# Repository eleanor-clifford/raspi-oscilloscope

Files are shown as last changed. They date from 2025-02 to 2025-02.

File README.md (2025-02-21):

| :exclamation:  | This is a mirror of [https://git.sr.ht/~ecc/raspi-oscilloscope](https://git.sr.ht/~ecc/raspi-oscilloscope). Please refrain from using GitHub's issue and PR system.  |
|---|:---|

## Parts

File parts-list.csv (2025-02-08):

Name | Part No. | Purpose | Value | Cost
RPi | RPi 1A rev 2 | Microprocessor | - | 0+
U1 | ECS-2200B-100 | Clock generator | 10 MHz | 1.96
U2 | TLC5510INSR | ADC | 20 MHz 8-bit parallel | 5.38
U3 | OPA690 | Op amp | 5V min unipolar | 3.01
U4 | SN74LS245N | Logic level converter | 5V - 3V3 | 2.99
D1 | NZX3V9C | ADC overvolt protection | 4V | 0.16
D2 | NZX5V1B | Op amp reverse/overvolt protection | 3V | 0.16
C1 | - | Input coupling | 100nF ceramic | 0+
C2 | - | Analog bypass | 100nF ceramic | 0+
C3 | - | Digital bypass | 100nF ceramic | 0+
C4 | - | Reference bypass | 100nF ceramic | 0+
C5 | - | Analog bypass | 4.7uF electrolytic | 0*
C6 | - | Digital bypass | 4.7uF electrolytic | 0*
C7 | - | Reference bypass | 4.7uF electrolytic | 0*
SW1 | SR10010F-0106-20F0B-C7-N-0027 | Op amp gain switch | SP6T | 5.19
R1 | - | Op amp gain (low) | 470 | 0+
R2 | - | ADC reference (high) | 82 | 0+
R3 | - | ADC reference (low) | 330 | 0+
R4 | - | Op amp bias (high) | 1.5k | 0+
R5 | - | Op amp bias (low) | 1k | 0+
R6 | - | Op amp input | 47 | 0+
R7 | - | ADC input | 47 | 0+
R8 | - | Op amp gain (10x) | 4k7 | 0+
R9 | - | Op amp gain (100x) | 47k | 0+
A1 | - | ADC adapter | SOP-24 to DIP-24 | 1.67-
A2 | - | Op amp adapter | SOP-4 to DIP-4 | 1.52-
B1 | PAD1 | Circuit board | DIP 31x19 | 3.42
J1 | 1-1337543-0 | Probe connector | BNC | 1.15
J2 | - | Data header | 1x8 2.54mm | 2.69-
J3 | - | Analog power header | 1x2 2.54mm | -
- | CQ4LF | Flux | Liquid, No-Clean | 6.30
- | CT2703 | Probe | 60MHz x1/x10 | 12.91
 |  |  | Total | 45.52
* | scavenged |  | VAT | 7.93
+ | bought earlier
- | includes extra components |  | Grand Total | 56.44

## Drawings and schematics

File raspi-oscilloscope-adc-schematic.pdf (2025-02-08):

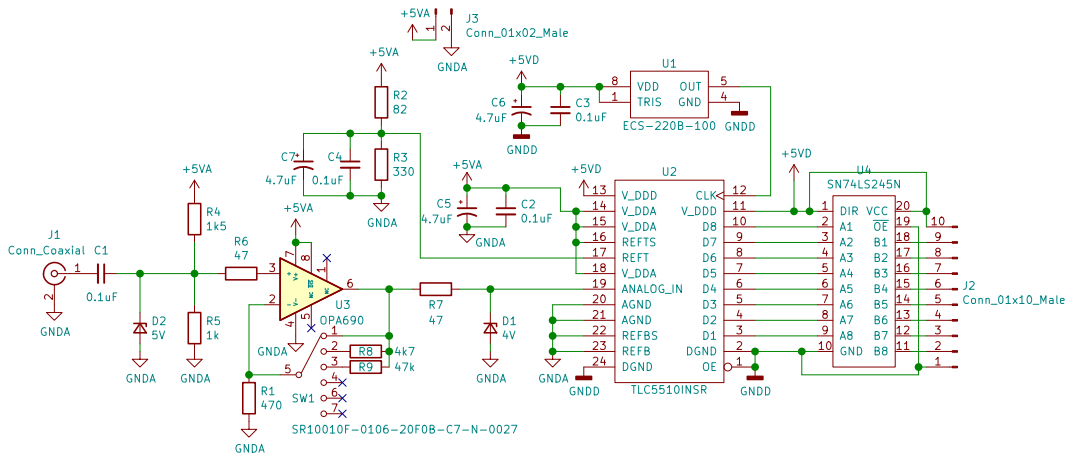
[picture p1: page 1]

Operates at 10Msps
Analog and digital power rails should ideally be isolated
Output will saturate at 4Vpp input
File: raspi-oscilloscope-adc.sch Sheet: / Designed by Tim Clifford

Id: 1/1 Title: Raspberry Pi oscilloscope ADC board

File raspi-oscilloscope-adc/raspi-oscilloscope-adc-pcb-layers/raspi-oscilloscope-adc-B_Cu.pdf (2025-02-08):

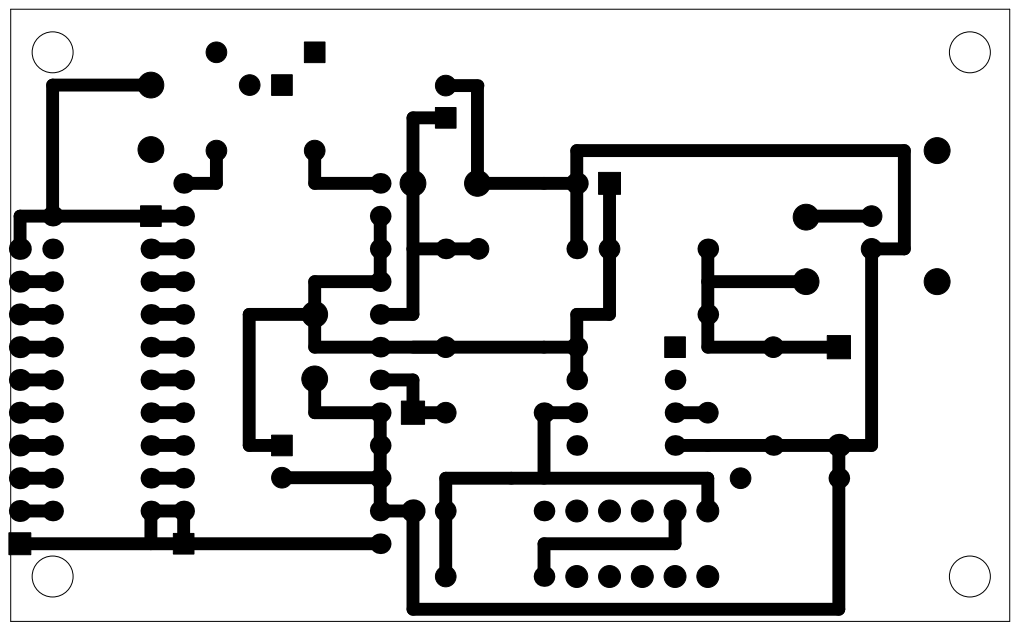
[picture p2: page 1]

Intended for implementation on 31x19 DIP busboard
Top level traces should be replaced by wires except around oscillator
U2 and U3 are intended as SOP packages on SOP-DIP adapters
File: raspi-oscilloscope-adc.kicad_pcb Sheet: Designed by Tim Clifford

Id: 1/1 Title: Raspberry Pi oscilloscope ADC board

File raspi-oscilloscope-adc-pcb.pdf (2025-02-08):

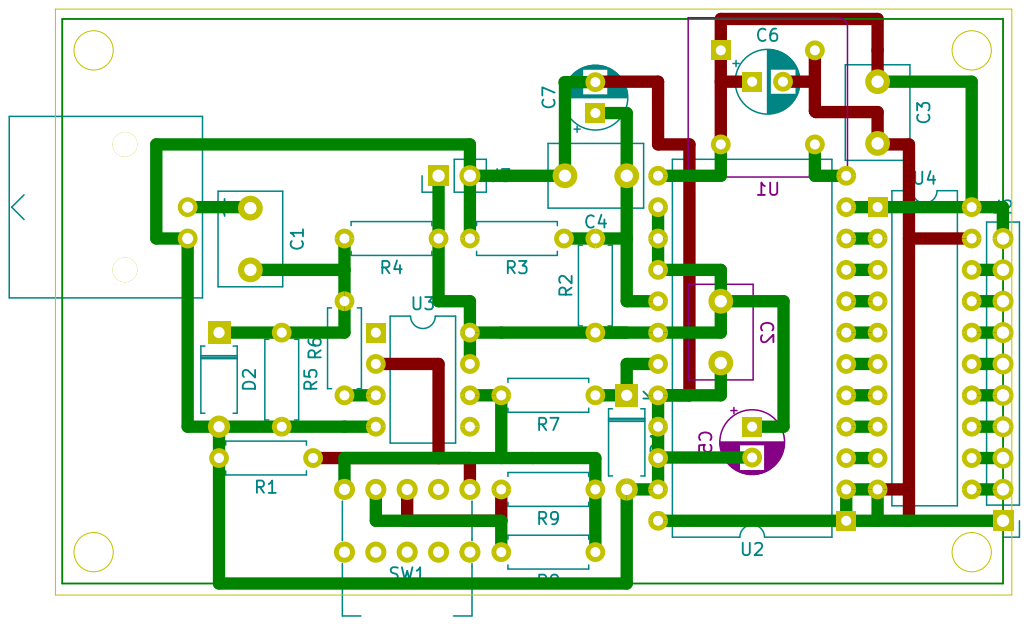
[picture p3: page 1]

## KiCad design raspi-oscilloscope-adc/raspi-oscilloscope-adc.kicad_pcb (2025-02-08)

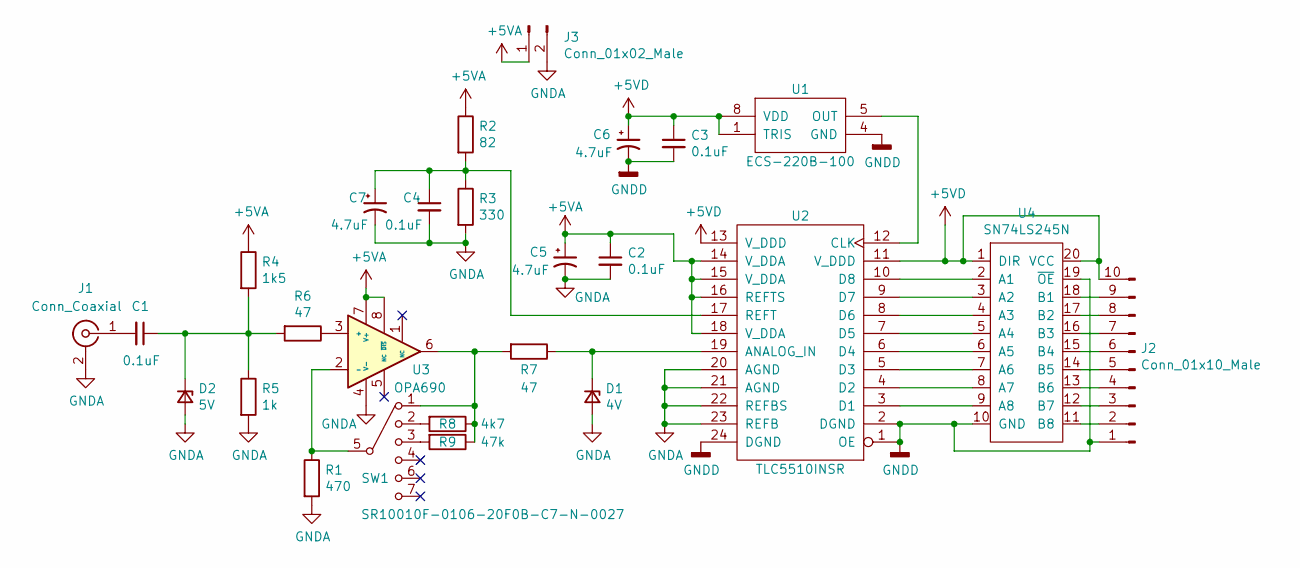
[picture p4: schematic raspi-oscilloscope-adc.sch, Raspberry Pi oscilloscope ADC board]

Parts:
C1, C2, C3, C4: 0.1uF; C_Disc_D7.5mm_W5.0mm_P5.00mm
C5, C6, C7: 4.7uF; CP_Radial_D5.0mm_P2.50mm
D1: 4V; D_A-405_P7.62mm_Horizontal
D2: 5V; D_A-405_P7.62mm_Horizontal
J1: Conn_Coaxial; 1-1337543-0
J2: Conn_01x10_Male; PinHeader_1x10_P2.54mm_Vertical
J3: Conn_01x02_Male; PinHeader_1x02_P2.54mm_Vertical
R1: 470; R_Axial_DIN0207_L6.3mm_D2.5mm_P7.62mm_Horizontal
R2: 82; R_Axial_DIN0207_L6.3mm_D2.5mm_P7.62mm_Horizontal
R3: 330; R_Axial_DIN0207_L6.3mm_D2.5mm_P7.62mm_Horizontal
R4: 1k5; R_Axial_DIN0207_L6.3mm_D2.5mm_P7.62mm_Horizontal
R5: 1k; R_Axial_DIN0207_L6.3mm_D2.5mm_P7.62mm_Horizontal
R6, R7: 47; R_Axial_DIN0207_L6.3mm_D2.5mm_P7.62mm_Horizontal
R8: 4k7; R_Axial_DIN0207_L6.3mm_D2.5mm_P7.62mm_Horizontal
R9: 47k; R_Axial_DIN0207_L6.3mm_D2.5mm_P7.62mm_Horizontal
SW1: SR10010F-0106-20F0B-C7-N-0027; SW_SP6T
U1: ECS-220B-100; Oscillator_DIP-8
U2: TLC5510INSR; DIP-24_W15.24mm
U3: OPA690; DIP-8_W7.62mm
U4: SN74LS245N; DIP-20_W7.62mm

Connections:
+5VA: C2.1, C5.1, J3.1, R2.1, R4.1, U2.14 (V_DDA), U2.15 (V_DDA), U2.16 (REFTS), U2.18 (V_DDA), U3.7 (V+), U3.8 (~DIS)
+5VD: C3.1, C6.1, J2.10, U1.1 (TRIS), U1.8 (VDD), U2.11 (V_DDD), U2.13 (V_DDD), U4.1 (DIR), U4.20 (VCC)
GNDA: C2.2, C4.2, C5.2, C7.2, D1.2 (A), D2.2 (A), J1.2 (Ext), J3.2, R1.2, R3.2, R5.2, U2.20 (AGND), U2.21 (AGND), U2.22 (REFBS), U2.23 (REFB), U3.4 (V-)
GNDD: C3.2, C6.2, J2.1, U1.4 (GND), U2.1 (OE), U2.2 (DGND), U2.24 (DGND), U4.10 (GND), U4.19 (~OE)
unnamed: C1.1, D2.1 (K), R4.2, R5.1, R6.2
unnamed: C1.2, J1.1 (In)
unnamed: C4.1, C7.1, R2.2, R3.1, U2.17 (REFT)
unnamed: D1.1 (K), R7.1, U2.19 (ANALOG_IN)
unnamed: J2.2, U4.11 (B8)
unnamed: J2.3, U4.12 (B7)
unnamed: J2.4, U4.13 (B6)
unnamed: J2.5, U4.14 (B5)
unnamed: J2.6, U4.15 (B4)
unnamed: J2.7, U4.16 (B3)
unnamed: J2.8, U4.17 (B2)
unnamed: J2.9, U4.18 (B1)
unnamed: R1.1, SW1.5, U3.2 (-)
unnamed: R6.1, U3.3 (+)
unnamed: R7.2, R8.1, R9.1, SW1.1, U3.6
unnamed: R8.2, SW1.2
unnamed: R9.2, SW1.3
unnamed: U1.5 (OUT), U2.12 (CLK)
unnamed: U2.3 (D1), U4.9 (A8)
unnamed: U2.4 (D2), U4.8 (A7)
unnamed: U2.5 (D3), U4.7 (A6)
unnamed: U2.6 (D4), U4.6 (A5)
unnamed: U2.7 (D5), U4.5 (A4)
unnamed: U2.8 (D6), U4.4 (A3)
unnamed: U2.9 (D7), U4.3 (A2)
unnamed: U2.10 (D8), U4.2 (A1)

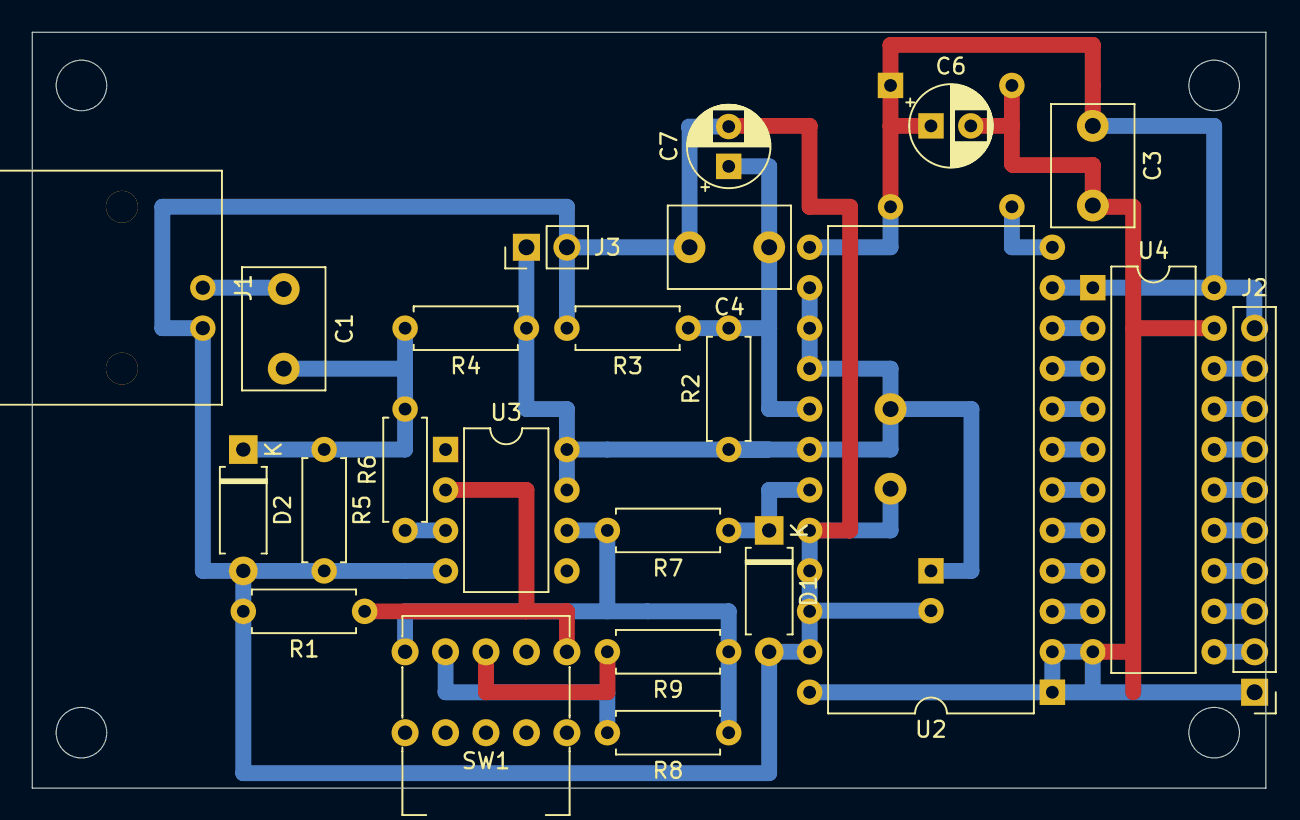
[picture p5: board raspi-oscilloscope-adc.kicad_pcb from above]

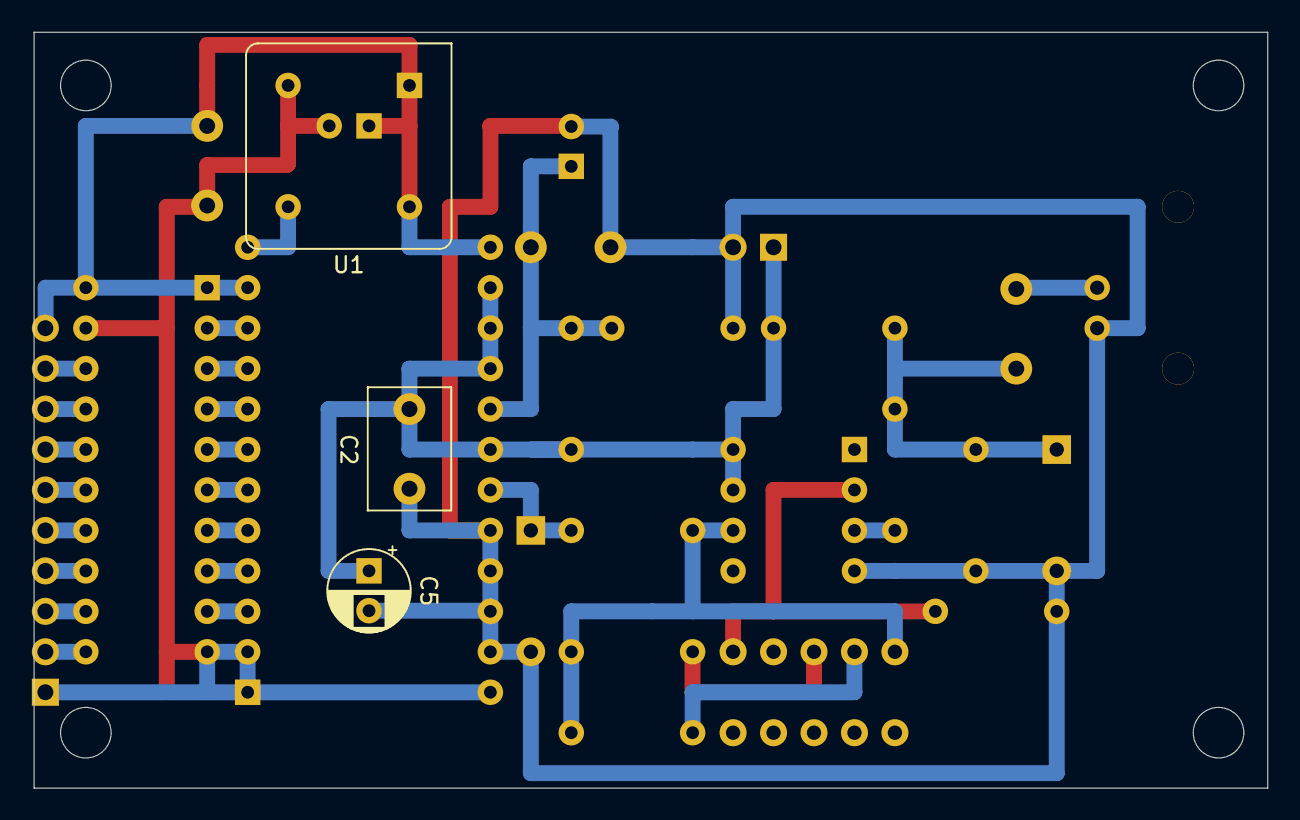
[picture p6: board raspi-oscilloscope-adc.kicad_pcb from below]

Board: 2 copper layers, 77.5 x 47.5 mm, 26 parts (3 on the bottom side), 30 nets.

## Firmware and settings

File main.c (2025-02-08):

//  GPIO Access macros
//  15-January-2012
//  Dom and Gert
//  Revised: 15-Feb-2013
// Access from ARM Running Linux

#define BCM2708_PERI_BASE        0x20000000
#define GPIO_BASE                (BCM2708_PERI_BASE + 0x200000) /* GPIO controller */

#include <stdio.h>
#include <stdlib.h>
#include <fcntl.h>
#include <sys/mman.h>
#include <sys/time.h>
#include <unistd.h>

#define PAGE_SIZE (4*1024)
#define BLOCK_SIZE (4*1024)

int  mem_fd;
void *gpio_map;

// I/O access
volatile unsigned *gpio;


// GPIO setup macros. Always use INP_GPIO(x) before using OUT_GPIO(x) or SET_GPIO_ALT(x,y)
#define INP_GPIO(g) *(gpio+((g)/10)) &= ~(7<<(((g)%10)*3))
#define OUT_GPIO(g) *(gpio+((g)/10)) |=  (1<<(((g)%10)*3))
#define SET_GPIO_ALT(g,a) *(gpio+(((g)/10))) |= (((a)<=3?(a)+4:(a)==4?3:2)<<(((g)%10)*3))

#define GPIO_SET *(gpio+7)  // sets   bits which are 1 ignores bits which are 0
#define GPIO_CLR *(gpio+10) // clears bits which are 1 ignores bits which are 0

#define GET_GPIO(g) (*(gpio+13)&(1<<g)) // 0 if LOW, (1<<g) if HIGH
#define GET_GPIO_ALL *(gpio+13)

#define GPIO_PULL *(gpio+37) // Pull up/pull down
#define GPIO_PULLCLK0 *(gpio+38) // Pull up/pull down clock


// Uses code from Raspberry Compote http://raspberrycompote.blogspot.com/2012/12/low-level-graphics-on-raspberry-pi-part_9509.html
// and glyphs from JSBallista https://github.com/JSBattista/Characters_To_Linux_Buffer_THE_HARD_WAY

#include <string.h>
#include <linux/fb.h>
#include <sys/ioctl.h>
#include <time.h>
#include <math.h>
#include "EngNotation.h"
// These are the sizes of the individual character arrays
#define CHAR_ARR__10x14 168
#define CHAR_HEIGHT 14
#define CHAR_WIDTH 10
#define CHAR_SPACING 15
const unsigned char *ascii_characters[256];	// Store the ASCII character set, but can have some elements blank
struct fb_var_screeninfo orig_vinfo;
struct fb_var_screeninfo vinfo;
struct fb_fix_screeninfo finfo;
long int screensize;
void setup_chars();
void display_ascii(char *fbp, char c, int x, int y);
void clear_framebuffer(char *fbp);
void draw_background(char *fbp, double t);
void draw_rising_trigger(char *fbp, u_int8_t *data, int data_len, u_int8_t trigger_low, u_int8_t trigger_high);
void setup_io();
void setup_framebuffer();
void cleanup_framebuffer();
char *fbp = 0;
int fbfd = 0;
void request_data(int data_len, int delay_usec, u_int8_t *data);

// application entry point
int main(int argc, char* argv[])
{
    srand(time(NULL));
    setup_chars();
    setup_framebuffer();
    setup_io();
    // scope time...
    u_int8_t *data = malloc(512*sizeof(u_int8_t));
    clear_framebuffer(fbp);
    // scope
	while (1) {
		draw_background(fbp, 1.234e-9);
		request_data(512,0,data);
		draw_rising_trigger(fbp,data,512,16,240);
		//printf("%x\n",data[256]);
	}
	free(data);
  //  sleep(5);

  	cleanup_framebuffer();
  	return 0;
}
void display_ascii(char *fbp, char c, int x, int y)
{
    int yi;
    for (yi = 0; yi < CHAR_HEIGHT; yi++) {
        memcpy((char*)(fbp + x + (y+yi)*finfo.line_length),(char*)(ascii_characters[c] + CHAR_WIDTH*yi),CHAR_WIDTH*sizeof(u_int8_t));
    }
}
void clear_framebuffer(char *fbp) {
	int i;
	for (i = 0; i < vinfo.yres*vinfo.xres; i++) fbp[i] = 0;
}
void draw_background(char *fbp, double t) {
    // create fixed background grid
    // we will use 512x256px for the actual trace, and a resolution of 640x360px
    // (8 bit ADC results in 256 levels so there's no point quantising to something else and losing information)
    // assume for now that timestep is constant t
    // although it defo won't be lol
    // lets split into 8x4 squares because why not. So lines at 64px and why not tick at 8px
    // leave 52px left/right and 64px up/down
    // i don't care too much about efficiency here because it will be executed infrequently
    int x,y;
    for (x = 52; x < 564; x++) {
        for (y = 64; y < 320; y++) {
            if ((x-52)%64 == 0 || y%64 == 0) fbp[x + y * finfo.line_length] = 2;
            else {
                int xrel = (x-52)%64;
                int yrel = y%64;
                if ((x-52)%8 == 0 && (yrel < 4 || yrel > 60)) fbp[x + y * finfo.line_length] = 2;
                if (y%8 == 0 && (xrel < 4 || xrel > 60)) fbp[x + y * finfo.line_length] = 2;
            }
        }
    }
    // write timestep in full up top then round for the markings
    char *t_eng_notation = to_engineering_string(t,8,0);
    char *test_string = "ABCDEFGHIJKkLMmNOPQRSsTUuVWXYZ\0";
    int i = 0;
    do {
        display_ascii(fbp, test_string[i], 10+i*CHAR_SPACING, 10);
    } while (test_string[++i] != '\0');
    char *test_string_2 = "0123456789\0";
    i = 0;
    do {
        display_ascii(fbp, test_string_2[i], 10+i*CHAR_SPACING, 30);
    } while (test_string_2[++i] != '\0');
	free(t_eng_notation);
}
void request_data(int data_len, int delay_usec, u_int8_t *data) {
	u_int16_t raw_data;
	int i;
	for (i=0; i<data_len; i++)
	{
		raw_data = GET_GPIO_ALL;
		data[i] = ((raw_data >> 4) & 248) | ((raw_data >> 2) & 7);
		if (delay_usec) usleep(delay_usec);
	}
}
void draw_rising_trigger(char *fbp, u_int8_t *data, int data_len, u_int8_t trigger_low, u_int8_t trigger_high) {
    /* Trigger the signal based on an average of the times 
     * when the signal passes a high and low trigger
     *  |   /\         |   /\ 
     *  |  /  \        |  /  \
     *  |_/____\_______|_/____\____ high trigger
     *  |/      \      |/      \
     *_/|________\____/|________\__ low trigger
     *  |         \  / |
     *  |          \/  |            vertical lines will be centered on screen
     * 
     * this allows noise within trigger levels without it spasming on screen
     *
     * making this low efficiency now, will have to optimise later
     * prioritise low memory use, since `data` should fill
     * as much of main memory as possible
     */
    // find rising edges
    int i,j;
    bool low = false; // data was above low trigger
    bool high = false; // data has hit high trigger (resets on low)
    int low_marker = 0; // the index where signal rose above low trigger
    int trigger_marker; // index to trigger on
    int t_scaling = 1; // we will want later to skip/amalgamate some of the datapoints to show higher frequencies
    int startval,endval;
    //int last_trigger = 0;
    //double t_avg = 0; // average period so far (in units of timestep)
    //int rise_counter = 0
    u_int8_t *linebuffer = calloc(512,sizeof(u_int8_t)); // buffer of last value drawn to screen at this position
    // this means we can erase and write at the same position with minimal latency so that something is on the screen at all times
    for (i = 0; i < data_len; i++) {
        //printf("i: %d, data: %d\n",i,data[i]);
        if (data[i] > trigger_high) {
            if (!high) {

                if (!low) {
                    low_marker = i;
                    low = true;
                }
                trigger_marker = (int)(i + low_marker)/2; // close enough
                //t_avg = (t_avg*(rise_counter++) + trigger_marker)/rise_counter;
                // for now, lets just redraw on every rising edge, but
                // in future it's not worth it when several waveforms may be on screen
                if (trigger_marker < 256) startval = 0;
                else startval = trigger_marker - 256;
                if (trigger_marker + 256 > data_len) endval = data_len-1;
                else endval = trigger_marker + 256;
                //printf("st: %d tr: %d en: %d\n",startval,trigger_marker,endval);
                //sleep(1);
                for (j = startval; j < endval; j++) {
                //    printf("j: %d data: %d\n",j,data[j]);
                    // clear the pixel at this point in the linebuffer
                    fbp[308 + j - trigger_marker + (64+linebuffer[256+j-trigger_marker]) * finfo.line_length] = 0;
                    // set new pixel
                    fbp[308 + j - trigger_marker + (64+data[j]) * finfo.line_length] = 1; // 308 = 52 + 256, 52 is zero point
                    // write into linebuffer at new position
                    linebuffer[256+j-trigger_marker] = data[j];
                }
                usleep(100000); // wait to make sure it actually shows up
				// just for debugging
				clear_framebuffer(fbp);

				draw_background(fbp,0);
                high = true; // now wait until below low
            }
        }
        else if (data[i] > trigger_low) {
            if (!low) {
                low = true; // data has hit low trigger
                low_marker = i;
            }
        }
        else {
            high = false;
            low = false;
        }
    }
	free(linebuffer);
     
}
void setup_io()
{
	/* open /dev/mem */
	if ((mem_fd = open("/dev/mem", O_RDWR|O_SYNC) ) < 0) {
		printf("can't open /dev/mem \n");
		exit(-1);
	}

	/* mmap GPIO */
	gpio_map = mmap(
	   NULL,             //Any adddress in our space will do
	   BLOCK_SIZE,       //Map length
	   PROT_READ|PROT_WRITE,// Enable reading & writting to mapped memory
	   MAP_SHARED,       //Shared with other processes
	   mem_fd,           //File to map
	   GPIO_BASE         //Offset to GPIO peripheral
	);

	close(mem_fd); //No need to keep mem_fd open after mmap

	if (gpio_map == MAP_FAILED) {
		printf("mmap error %d\n", (int)gpio_map);//errno also set!
		exit(-1);
	}

   // Always use volatile pointer!
   gpio = (volatile unsigned *)gpio_map;
   
   // set inputs from ADC
   int g;
   for (g=2; g<= 4; g++) INP_GPIO(g);
   for (g=7; g<=11; g++) INP_GPIO(g);

}
void setup_framebuffer() {
  
  screensize = 0;
  // Open the file for reading and writing
  fbfd = open("/dev/fb0", O_RDWR);
  if (!fbfd) {
    printf("Error: cannot open framebuffer device.\n");
    exit(1);
  }
  printf("The framebuffer device was opened successfully.\n");

  // Get variable screen information
  if (ioctl(fbfd, FBIOGET_VSCREENINFO, &vinfo)) {
    printf("Error reading variable information.\n");
  }
  printf("Original %dx%d, %dbpp\n", vinfo.xres, vinfo.yres, 
         vinfo.bits_per_pixel );

  // Store for reset (copy vinfo to vinfo_orig)
  memcpy(&orig_vinfo, &vinfo, sizeof(struct fb_var_screeninfo));

  // Change variable info
  vinfo.bits_per_pixel = 8;
  if (ioctl(fbfd, FBIOPUT_VSCREENINFO, &vinfo)) {
    printf("Error setting variable information.\n");
  }
  
  // Get fixed screen information
  if (ioctl(fbfd, FBIOGET_FSCREENINFO, &finfo)) {
    printf("Error reading fixed information.\n");
  }

  // map fb to user mem 
  screensize = finfo.smem_len;
  fbp = (char*)mmap(0, 
                    screensize, 
                    PROT_READ | PROT_WRITE, 
                    MAP_SHARED, 
                    fbfd, 
                    0);

  if ((int)fbp == -1) {
    printf("Failed to mmap.\n");
	exit(1);
  }
}
void cleanup_framebuffer() {
	// cleanup
  	munmap(fbp, screensize);
  	if (ioctl(fbfd, FBIOPUT_VSCREENINFO, &orig_vinfo)) {
    	printf("Error re-setting variable information.\n");
  	}
  	close(fbfd);
}
void setup_chars()
{
	{
		const unsigned char A__10x14[CHAR_ARR__10x14] = {
							        				0,0,0,0,1,1,0,0,0,0,
									        		0,0,0,1,1,1,1,0,0,0,
        											0,0,1,1,1,1,1,1,0,0,
		        									0,1,1,1,0,0,1,1,1,0,
				        							1,1,1,0,0,0,0,1,1,1,
						        					1,1,0,0,0,0,0,0,1,1,
								        			1,1,0,0,0,0,0,0,1,1,
										        	1,1,0,0,0,0,0,0,1,1,
        											1,1,1,1,1,1,1,1,1,1,
		        									1,1,1,1,1,1,1,1,1,1,
				        							1,1,0,0,0,0,0,0,1,1,
						        					1,1,0,0,0,0,0,0,1,1,
								        			1,1,0,0,0,0,0,0,1,1,
										        	1,1,0,0,0,0,0,0,1,1
		};
		const unsigned char B__10x14[CHAR_ARR__10x14] = {
													1,1,1,1,1,1,1,0,0,0,
													1,1,1,1,1,1,1,1,1,0,
													1,1,0,0,0,0,0,1,1,1,
													1,1,0,0,0,0,0,0,1,1,
													1,1,0,0,0,0,0,0,1,1,
													1,1,0,0,0,0,0,1,1,1,
													1,1,1,1,1,1,1,1,1,0,
													1,1,1,1,1,1,1,1,0,0,
													1,1,0,0,0,0,0,1,1,0,
													1,1,0,0,0,0,0,0,1,1,
													1,1,0,0,0,0,0,0,1,1,
													1,1,0,0,0,0,0,0,1,1,
													1,1,0,0,0,0,0,1,1,0,
													1,1,1,1,1,1,1,0,0,0
		};
		const unsigned char C__10x14[CHAR_ARR__10x14] = {
													0,0,0,1,1,1,1,1,0,0,
													0,0,1,1,1,1,1,1,0,0,
													1,1,1,0,0,0,0,1,1,0,
													1,1,0,0,0,0,0,0,1,1,
													1,1,0,0,0,0,0,0,1,1,
													1,1,0,0,0,0,0,0,0,0,
													1,1,0,0,0,0,0,0,0,0,
													1,1,0,0,0,0,0,0,0,0,
													1,1,0,0,0,0,0,0,0,0,
													1,1,0,0,0,0,0,0,1,1,
													1,1,0,0,0,0,0,0,1,1,
													1,1,1,0,0,0,0,1,1,0,
													0,0,1,1,1,1,1,1,0,0,
													0,0,0,1,1,1,1,1,0,0
		};
		const unsigned char D__10x14[CHAR_ARR__10x14] = {
													1,1,1,1,1,1,1,0,0,0,
													1,1,1,1,1,1,1,1,1,0,
													1,1,0,0,0,0,0,1,1,1,
													1,1,0,0,0,0,0,0,1,1,
													1,1,0,0,0,0,0,0,1,1,
													1,1,0,0,0,0,0,0,1,1,
													1,1,0,0,0,0,0,0,1,1,
													1,1,0,0,0,0,0,0,1,1,
													1,1,0,0,0,0,0,0,1,1,
													1,1,0,0,0,0,0,0,1,1,
													1,1,0,0,0,0,0,0,1,1,
													1,1,0,0,0,0,0,0,1,1,
													1,1,0,0,0,0,0,1,1,1,
													1,1,1,1,1,1,1,0,0,0
		};
		const unsigned char E__10x14[CHAR_ARR__10x14] = {
													1,1,1,1,1,1,1,1,1,1,
													1,1,1,1,1,1,1,1,1,1,
													1,1,0,0,0,0,0,0,0,0,
													1,1,0,0,0,0,0,0,0,0,
													1,1,0,0,0,0,0,0,0,0,
													1,1,0,0,0,0,0,0,0,0,
													1,1,1,1,1,1,1,1,0,0,
													1,1,1,1,1,1,1,1,0,0,
													1,1,0,0,0,0,0,0,0,0,
													1,1,0,0,0,0,0,0,0,0,
													1,1,0,0,0,0,0,0,0,0,
													1,1,0,0,0,0,0,0,0,0,
													1,1,1,1,1,1,1,1,1,1,
													1,1,1,1,1,1,1,1,1,1
		};
		const unsigned char F__10x14[CHAR_ARR__10x14] = {
													1,1,1,1,1,1,1,1,1,1,
													1,1,1,1,1,1,1,1,1,1,
													1,1,0,0,0,0,0,0,0,0,
													1,1,0,0,0,0,0,0,0,0,
													1,1,0,0,0,0,0,0,0,0,
													1,1,0,0,0,0,0,0,0,0,
													1,1,1,1,1,1,1,1,0,0,
													1,1,1,1,1,1,1,1,0,0,
													1,1,0,0,0,0,0,0,0,0,
													1,1,0,0,0,0,0,0,0,0,
													1,1,0,0,0,0,0,0,0,0,
													1,1,0,0,0,0,0,0,0,0,
													1,1,0,0,0,0,0,0,0,0,
													1,1,0,0,0,0,0,0,0,0
		};
		const unsigned char G__10x14[CHAR_ARR__10x14] = {
													0,0,0,1,1,1,1,1,0,0,
													0,0,1,1,1,1,1,1,0,0,
													1,1,1,0,0,0,0,1,1,0,
													1,1,0,0,0,0,0,0,1,1,
													1,1,0,0,0,0,0,0,1,1,
													1,1,0,0,0,0,0,0,0,0,
													1,1,0,0,0,0,0,0,0,0,
													1,1,0,0,0,0,0,0,0,0,
													1,1,0,0,0,0,0,0,0,0,
													1,1,0,0,0,1,1,1,1,1,
													1,1,0,0,0,1,1,1,1,1,
													1,1,1,0,0,0,0,1,1,1,
													0,0,1,1,1,1,1,1,0,0,
													0,0,0,1,1,1,1,1,0,0
		};
		const unsigned char H__10x14[CHAR_ARR__10x14] = {
													1,1,0,0,0,0,0,0,1,1,
													1,1,0,0,0,0,0,0,1,1,
													1,1,0,0,0,0,0,0,1,1,
													1,1,0,0,0,0,0,0,1,1,
													1,1,0,0,0,0,0,0,1,1,
													1,1,0,0,0,0,0,0,1,1,
													1,1,1,1,1,1,1,1,1,1,
													1,1,1,1,1,1,1,1,1,1,
													1,1,0,0,0,0,0,0,1,1,
													1,1,0,0,0,0,0,0,1,1,
													1,1,0,0,0,0,0,0,1,1,
													1,1,0,0,0,0,0,0,1,1,
													1,1,0,0,0,0,0,0,1,1,
													1,1,0,0,0,0,0,0,1,1
		};
		const unsigned char I__10x14[CHAR_ARR__10x14] = {
													1,1,1,1,1,1,1,1,1,1,
													1,1,1,1,1,1,1,1,1,1,
													0,0,0,0,1,1,0,0,0,0,
													0,0,0,0,1,1,0,0,0,0,
													0,0,0,0,1,1,0,0,0,0,
													0,0,0,0,1,1,0,0,0,0,
													0,0,0,0,1,1,0,0,0,0,
													0,0,0,0,1,1,0,0,0,0,
													0,0,0,0,1,1,0,0,0,0,
													0,0,0,0,1,1,0,0,0,0,
													0,0,0,0,1,1,0,0,0,0,
													0,0,0,0,1,1,0,0,0,0,
													1,1,1,1,1,1,1,1,1,1,
													1,1,1,1,1,1,1,1,1,1
		};
		const unsigned char J__10x14[CHAR_ARR__10x14] = {
													1,1,1,1,1,1,1,1,1,1,
													1,1,1,1,1,1,1,1,1,1,
													0,0,0,0,1,1,0,0,0,0,
													0,0,0,0,1,1,0,0,0,0,
													0,0,0,0,1,1,0,0,0,0,
													0,0,0,0,1,1,0,0,0,0,
													0,0,0,0,1,1,0,0,0,0,
													0,0,0,0,1,1,0,0,0,0,
													0,0,0,0,1,1,0,0,0,0,
													0,0,0,0,1,1,0,0,0,0,
													1,1,0,0,1,1,0,0,0,0,
													1,1,0,0,1,1,0,0,0,0,
													0,1,1,1,1,1,0,0,0,0,
													0,0,1,1,1,0,0,0,0,0
		};
		const unsigned char K__10x14[CHAR_ARR__10x14] = {
													1,1,0,0,0,0,0,0,1,1,
													1,1,0,0,0,0,0,1,1,0,
													1,1,0,0,0,0,1,1,0,0,
													1,1,0,0,0,1,1,0,0,0,
													1,1,0,0,1,1,0,0,0,0,
													1,1,1,1,1,0,0,0,0,0,
													1,1,1,1,0,0,0,0,0,0,
													1,1,1,1,0,0,0,0,0,0,
													1,1,1,1,0,0,0,0,0,0,
													1,1,0,1,1,0,0,0,0,0,
													1,1,0,0,1,1,0,0,0,0,
													1,1,0,0,0,0,1,1,0,0,
													1,1,0,0,0,0,0,1,1,0,
													1,1,0,0,0,0,0,0,1,1
		};
		const unsigned char L__10x14[CHAR_ARR__10x14] = {
													1,1,0,0,0,0,0,0,0,0,
													1,1,0,0,0,0,0,0,0,0,
													1,1,0,0,0,0,0,0,0,0,
													1,1,0,0,0,0,0,0,0,0,
													1,1,0,0,0,0,0,0,0,0,
													1,1,0,0,0,0,0,0,0,0,
													1,1,0,0,0,0,0,0,0,0,
													1,1,0,0,0,0,0,0,0,0,
													1,1,0,0,0,0,0,0,0,0,
													1,1,0,0,0,0,0,0,0,0,
													1,1,0,0,0,0,0,0,0,0,
													1,1,0,0,0,0,0,0,0,0,
													1,1,1,1,1,1,1,1,1,1,
													1,1,1,1,1,1,1,1,1,1
		};
		const unsigned char M__10x14[CHAR_ARR__10x14] = {
													1,1,0,0,0,0,0,0,1,1,
													1,1,1,0,0,0,0,1,1,1,
													1,1,1,1,0,0,1,1,1,1,
													1,1,0,1,1,1,1,0,1,1,
													1,1,0,0,1,1,0,0,1,1,
													1,1,0,0,1,1,0,0,1,1,
													1,1,0,0,0,0,0,0,1,1,
													1,1,0,0,0,0,0,0,1,1,
													1,1,0,0,0,0,0,0,1,1,
													1,1,0,0,0,0,0,0,1,1,
													1,1,0,0,0,0,0,0,1,1,
													1,1,0,0,0,0,0,0,1,1,
													0,1,0,0,0,0,0,0,1,1,
													1,1,0,0,0,0,0,0,1,1
		};
		const unsigned char N__10x14[CHAR_ARR__10x14] = {
													1,1,0,0,0,0,0,0,1,1,
													1,1,0,0,0,0,0,0,1,1,
													1,1,0,0,0,0,0,0,1,1,
													1,1,1,0,0,0,0,0,1,1,
													1,1,1,1,0,0,0,0,1,1,
													1,1,1,1,1,0,0,0,1,1,
													1,1,0,1,1,1,0,0,1,1,
													1,1,0,0,1,1,1,0,1,1,
													1,1,0,0,0,1,1,1,1,1,
													1,1,0,0,0,0,1,1,1,1,
													1,1,0,0,0,0,0,1,1,1,
													1,1,0,0,0,0,0,0,1,1,
													1,1,0,0,0,0,0,0,1,1,
													1,1,0,0,0,0,0,0,1,1
		};
		const unsigned char O__10x14[CHAR_ARR__10x14] = {
													0,0,1,1,1,1,1,1,0,0,
													0,1,1,1,1,1,1,1,1,0,
													1,1,1,0,0,0,0,1,1,1,
													1,1,0,0,0,0,0,0,1,1,
													1,1,0,0,0,0,0,0,1,1,
													1,1,0,0,0,0,0,0,1,1,
													1,1,0,0,0,0,0,0,1,1,
													1,1,0,0,0,0,0,0,1,1,
													1,1,0,0,0,0,0,0,1,1,
													1,1,0,0,0,0,0,0,1,1,
													1,1,0,0,0,0,0,0,1,1,
													1,1,1,0,0,0,0,1,1,1,
													0,1,1,1,1,1,1,1,1,0,
													0,0,1,1,1,1,1,1,0,0
		};
		const unsigned char P__10x14[CHAR_ARR__10x14] = {
													1,1,1,1,1,1,1,1,0,0,
													1,1,1,1,1,1,1,1,0,0,
													1,1,0,0,0,0,0,1,1,0,
													1,1,0,0,0,0,0,0,1,1,
													1,1,0,0,0,0,0,0,1,1,
													1,1,0,0,0,0,0,1,1,0,
													1,1,1,1,1,1,1,1,0,0,
													1,1,1,1,1,1,1,0,0,0,
													1,1,0,0,0,0,0,0,0,0,
													1,1,0,0,0,0,0,0,0,0,
													1,1,0,0,0,0,0,0,0,0,
													1,1,0,0,0,0,0,0,0,0,
													1,1,0,0,0,0,0,0,0,0,
													1,1,0,0,0,0,0,0,0,0
		};
		const unsigned char Q__10x14[CHAR_ARR__10x14] = {
													0,0,1,1,1,1,1,1,0,0,
													0,1,1,1,1,1,1,1,1,0,
													1,1,1,0,0,0,0,1,1,1,
													1,1,0,0,0,0,0,0,1,1,
													1,1,0,0,0,0,0,0,1,1,
													1,1,0,0,0,0,0,0,1,1,
													1,1,0,0,0,0,0,0,1,1,
													1,1,0,0,0,0,0,0,1,1,
													1,1,0,0,0,0,0,0,1,1,
													1,1,0,0,1,1,1,0,1,1,
													1,1,0,0,0,1,1,1,1,1,
													1,1,1,0,0,0,1,1,1,1,
													0,1,1,1,1,1,1,1,1,1,
													0,0,1,1,1,1,1,1,1,1
		};
        const unsigned char R__10x14[CHAR_ARR__10x14] = {
													1,1,1,1,1,1,1,1,0,0,
													1,1,1,1,1,1,1,1,0,0,
													1,1,0,0,0,0,0,1,1,0,
													1,1,0,0,0,0,0,0,1,1,
													1,1,0,0,0,0,0,0,1,1,
													1,1,0,0,0,0,0,1,1,0,
													1,1,1,1,1,1,1,1,0,0,
													1,1,1,1,1,1,1,0,0,0,
													1,1,0,1,1,1,0,0,0,0,
													1,1,0,0,0,1,1,0,0,0,
													1,1,0,0,0,0,1,1,0,0,
													1,1,0,0,0,0,0,1,1,0,
													1,1,0,0,0,0,0,0,1,1,
													1,1,0,0,0,0,0,0,1,1
		};
		const unsigned char S__10x14[CHAR_ARR__10x14] = {
													0,0,0,1,1,1,1,0,0,0,
													0,0,1,1,1,1,1,1,0,0,
													0,1,1,0,0,0,1,1,1,0,
													1,1,0,0,0,0,0,0,1,1,
													1,1,0,0,0,0,0,0,0,0,
													1,1,1,0,0,0,0,0,0,0,
													0,1,1,1,1,1,1,0,0,0,
													0,0,1,1,1,1,1,1,0,0,
													0,0,0,0,0,0,0,1,1,0,
													0,0,0,0,0,0,0,0,1,1,
													1,1,0,0,0,0,0,0,1,1,
													1,1,1,0,0,0,0,1,1,0,
													0,0,1,1,1,1,1,1,0,0,
													0,0,0,1,1,1,1,0,0,0
		};
		const unsigned char T__10x14[CHAR_ARR__10x14] = {
													1,1,1,1,1,1,1,1,1,1,
													1,1,1,1,1,1,1,1,1,1,
													0,0,0,0,1,1,0,0,0,0,
													0,0,0,0,1,1,0,0,0,0,
													0,0,0,0,1,1,0,0,0,0,
													0,0,0,0,1,1,0,0,0,0,
													0,0,0,0,1,1,0,0,0,0,
													0,0,0,0,1,1,0,0,0,0,
													0,0,0,0,1,1,0,0,0,0,
													0,0,0,0,1,1,0,0,0,0,
													0,0,0,0,1,1,0,0,0,0,
													0,0,0,0,1,1,0,0,0,0,
													0,0,0,0,1,1,0,0,0,0,
													0,0,0,0,1,1,0,0,0,0
		};
		const unsigned char U__10x14[CHAR_ARR__10x14] = {
													1,1,0,0,0,0,0,0,1,1,
													1,1,0,0,0,0,0,0,1,1,
													1,1,0,0,0,0,0,0,1,1,
													1,1,0,0,0,0,0,0,1,1,
													1,1,0,0,0,0,0,0,1,1,
													1,1,0,0,0,0,0,0,1,1,
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

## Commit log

2025-02-08 framebuffer control testing
2025-02-08 more framebuffer stuff
2025-02-08 Wiring diagram
2025-02-08 Cleanup but probs added lots of bugs
    [main.c]
2025-02-08 Add over/reverse voltage protection diode and smoothing capacitors to schematic
2025-02-08 Improve schematic and add parts list
    [parts-list.csv]
2025-02-08 Finalise parts list; move to kicad; improve schematic; create pcb layout
    [parts-list.csv, raspi-oscilloscope-adc.kicad_pcb, raspi-oscilloscope-adc.sch]
2025-02-08 Tidy up
    [raspi-oscilloscope-adc.kicad_pcb, raspi-oscilloscope-adc.sch]
2025-02-08 Realign pcb to grid
    [raspi-oscilloscope-adc.kicad_pcb]
2025-02-08 Add 5V to 3V3 logic converter
    [parts-list.csv, raspi-oscilloscope-adc.kicad_pcb, raspi-oscilloscope-adc.sch]
2025-02-08 Board update
2025-02-08 Fix error in board
    [raspi-oscilloscope-adc.kicad_pcb]
